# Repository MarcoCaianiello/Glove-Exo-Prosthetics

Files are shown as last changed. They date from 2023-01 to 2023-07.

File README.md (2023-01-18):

# Glove-Exo-Prosthetics
## Project Developed @[Icaros-Lab](https://www.icaros.unina.it/)

The aim of the project is to develop an Hand-Shape Exoskeleton to assist a thumb-missing patience with limited hand mobility. The Exoskeleton have to assist the user in the grasp motion. The patient is a 60+ y.o. male, thumb amputee with broken tendons on the remaining fingers. They can be barely moved without hurts the patience. He show problem also at his wrist, he has not a free wrist motion and he cannot put in that too much force.

The Exoskeleton is fully passive and body-powered. We have identified the flexion/extension of the elbow has movement to link with the hand closing/opening. The structure of the device will be compliace to increase the patience comfort while it is wearing. The motion is trasmitted by nylon wire that run through 3D printed tendon guide until the prosthetic thumb, the index and medium finger tip. The tendon guides has been designed to not affect the grasping even if they are placed in iternal part of the hand: palm, finger tips and phalanges. To convert the elbow extension to an hand grasp, we anchor a main tendon on the patience's bicep. A second anchor point, link to the finger tendons is placed on the forearm. In this way, the tendos are pulled when the elbow is extended.

To replace the absence of the thumb, two different designs are proposed. "Thumb whole with hinge" is a one-part thumb, printed using TPU that is using the inner elasticity of TPU to form its joints. "Thumb bottom part" & "thumb top part" are two parts, printed in resin, of a solid thumb and are connected using hinges printed in TPU as joints. Both designs are mounted on a 3d printed splint, that is supposed to hug the back of the hand and offer stability to the prosthetic thumb. The splint and the glove are sewn together. The splint design can be found as "Splint"

To keep the grasp, even when the patient's elbow is flexed, some latching mechanisms are proposed. "Linear latch" has the disadvantage that it needs to be more than double in length compared to the maximum travelling distance. "Rotating latch" needs calibration and scaling to match perfectly the travelling distance of the tendon. An exoskeleton developed by "openbionics" is using a latch mechanism that could be used and can be found [here](https://github.com/OpenBionics/Body-Powered-Exoskeleton-Glove).

### Notes
- The glove must be comfortable and garantee grip during grasping
- The glove can be coated by silicon to increase the grip
- In the grasping movement, the metacarpal flexion has to be included
- The Splint cannot be fully rigid, must introduce a compliance struture to increase the comfort and the fit
- To avoid the interaction of the tendons and the velcro strap used on the Splint, an upgrade could be to eliminate the velcro strap at all on the hand. In this case the thumb will be fixed on the glove.
- The use of a differential, pretension or elastic tendons must be explored to compensate the different finger lengths.

This project is based on this first [prototype](https://github.com/petrokal/ICAROS).

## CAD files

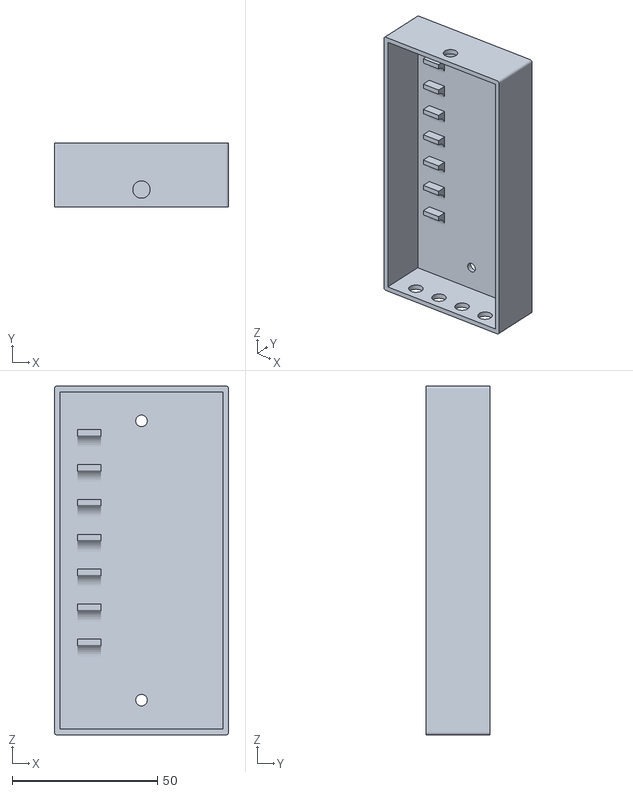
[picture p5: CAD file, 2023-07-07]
Latching_mechanism/Locker mechanism/Progetto locker con bottone/Scatola di fissaggio bottone v1.stl
60.0 x 22.0 x 120.0

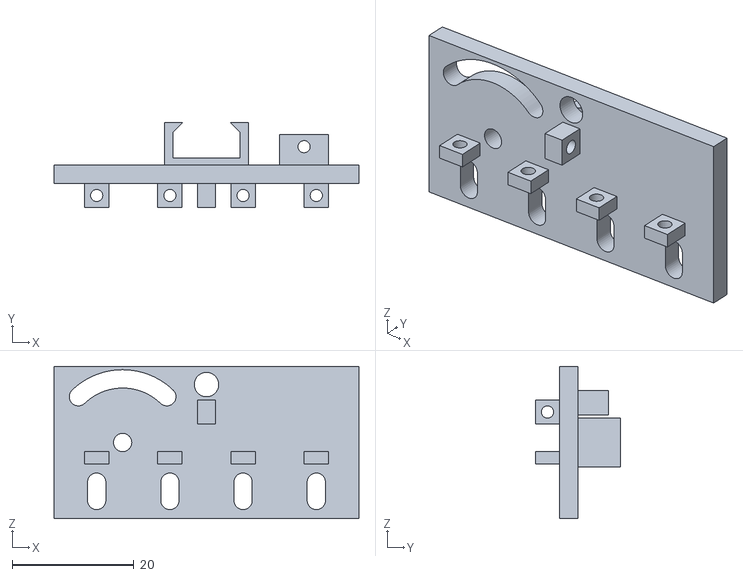
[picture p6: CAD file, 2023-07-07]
Latching_mechanism/Locker mechanism/Progetto locker-senza bottone/Base mobile v1.stl
50.0 x 14.0 x 25.0

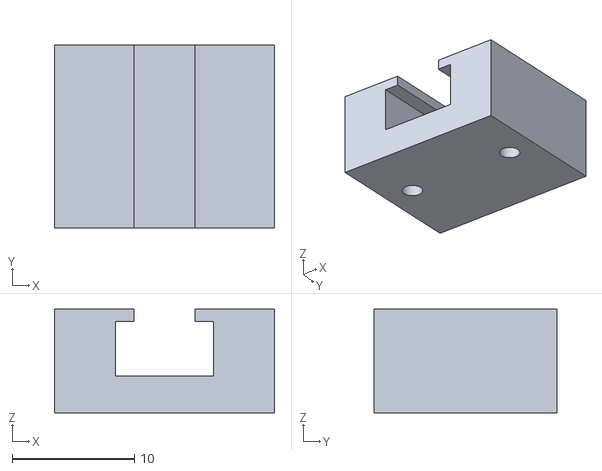
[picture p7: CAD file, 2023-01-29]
Latching_mechanism/openbionics/guide.stl
18.0 x 15.0 x 8.50

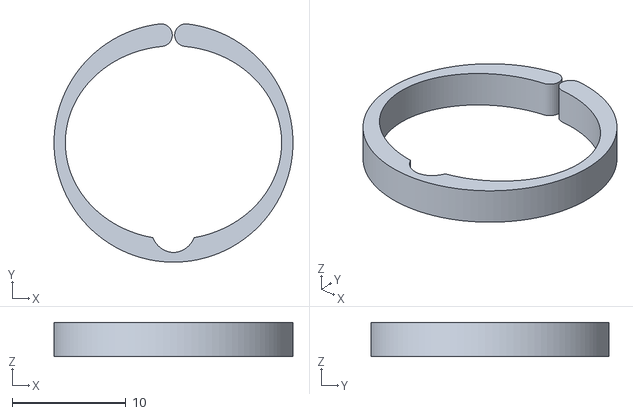
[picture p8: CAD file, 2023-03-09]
Tendon_guide/anchor_ring6.stl
21.0 x 20.9 x 3.00

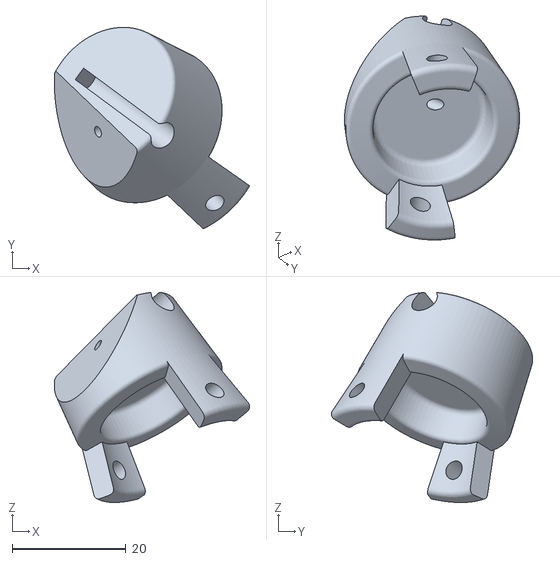
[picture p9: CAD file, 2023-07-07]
Thumb_Base_Wrist/Thumb_Base_mod.stl
34.4 x 35.4 x 37.0

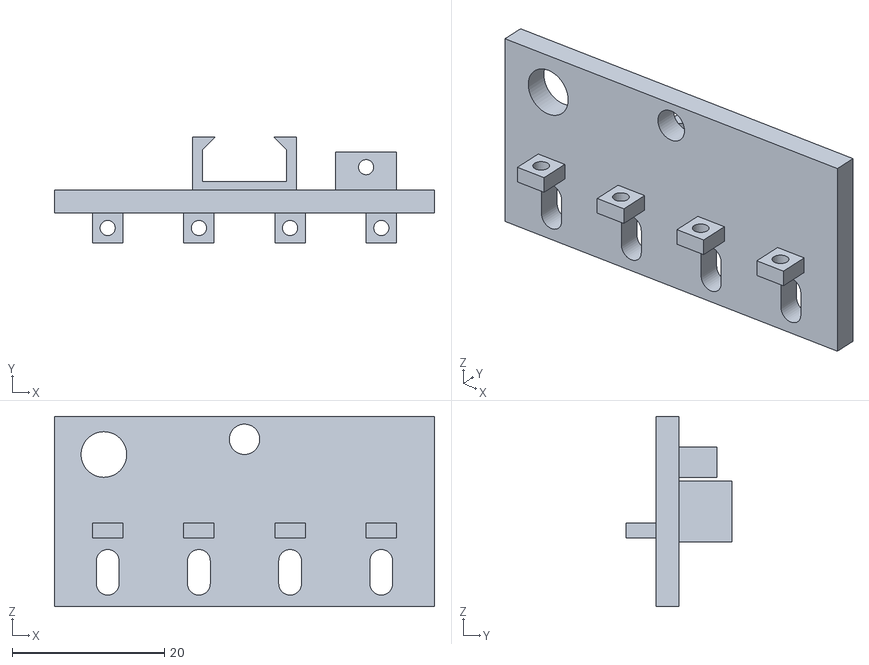
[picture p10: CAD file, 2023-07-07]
Latching_mechanism/Locker mechanism/Progetto locker con bottone/Base mobile bottone v1.stl
50.0 x 14.0 x 25.0

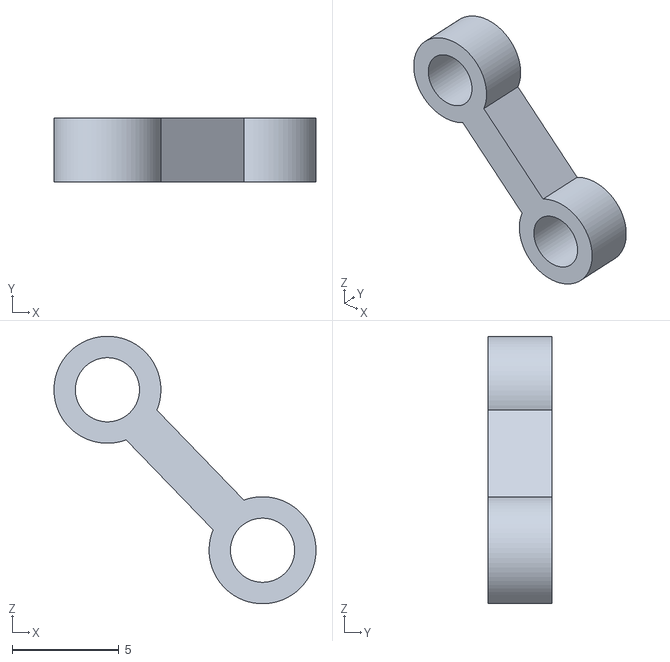
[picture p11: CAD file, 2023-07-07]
Latching_mechanism/Locker mechanism/Progetto locker-senza bottone/Perno rotante v1.stl
12.2 x 3.00 x 12.5

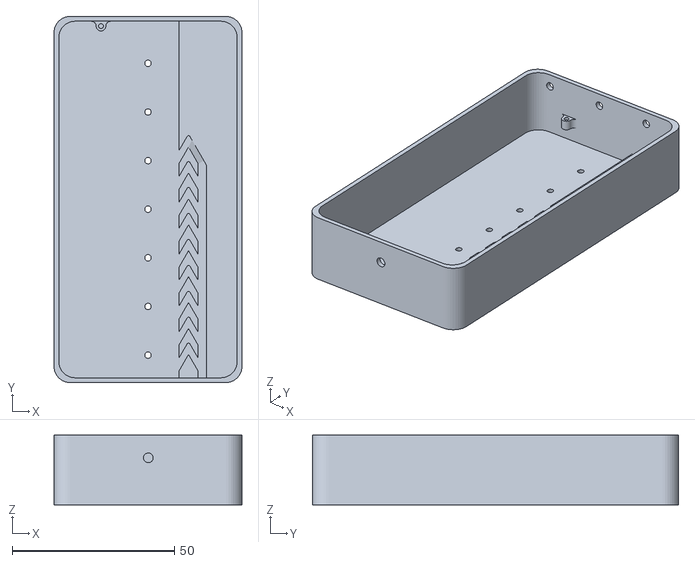
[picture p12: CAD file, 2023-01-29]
Latching_mechanism/openbionics/Box.STL
58.0 x 113.0 x 21.5

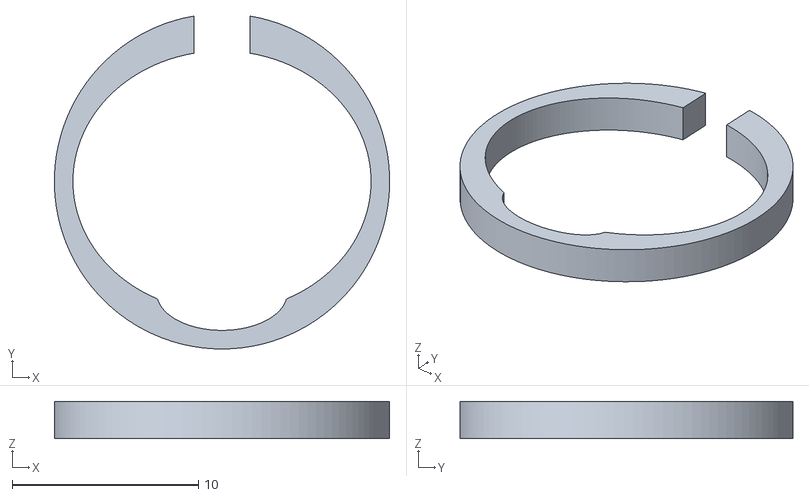
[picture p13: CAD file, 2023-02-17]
Tendon_guide/anchor_ring3.stl
18.0 x 17.9 x 2.00

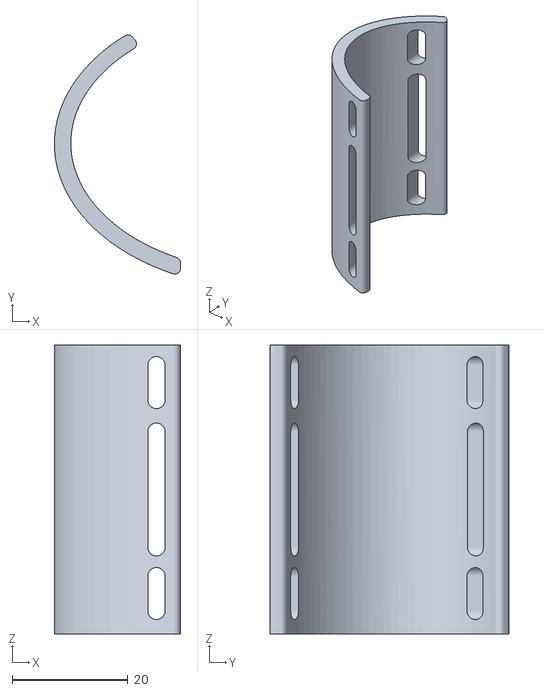
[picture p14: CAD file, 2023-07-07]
Thumb_Base_Wrist/Thumb_Wrist_Support_part2 v2.stl
21.8 x 41.4 x 50.0

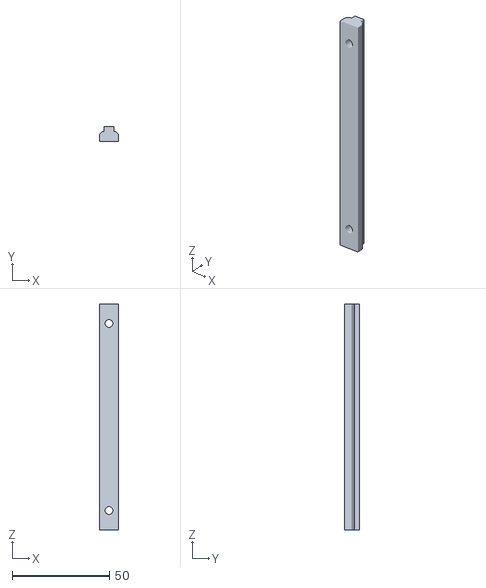
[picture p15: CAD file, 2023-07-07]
Latching_mechanism/Locker mechanism/Progetto locker-senza bottone/Guida lineare v1.stl
10.0 x 7.50 x 116.0

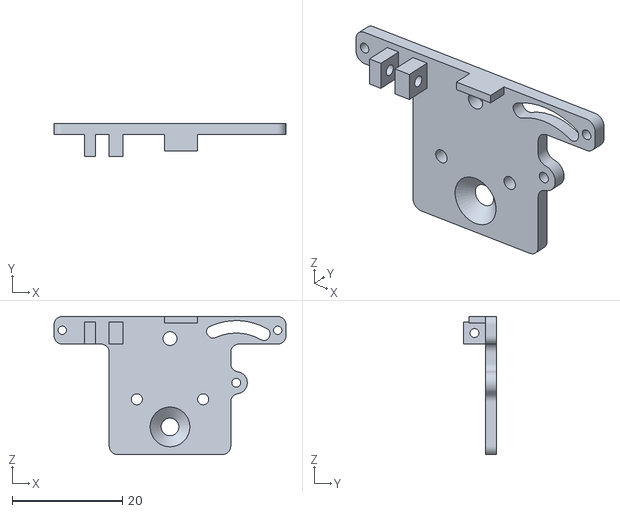
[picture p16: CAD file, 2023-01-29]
Latching_mechanism/openbionics/Rail attachment.STL
42.0 x 6.00 x 25.0

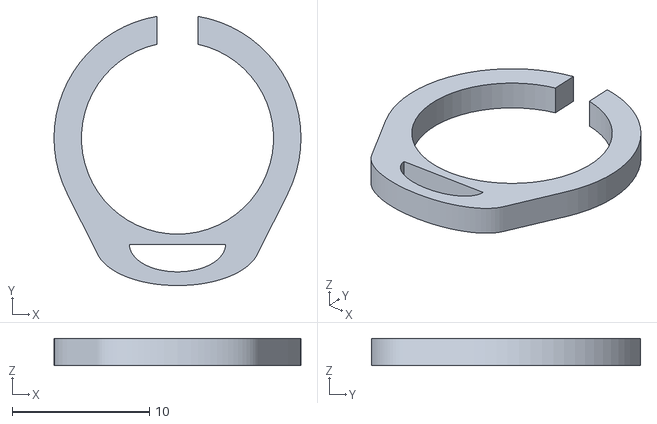
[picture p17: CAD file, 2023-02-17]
Tendon_guide/anchor_ring2.stl
18.0 x 19.6 x 2.00

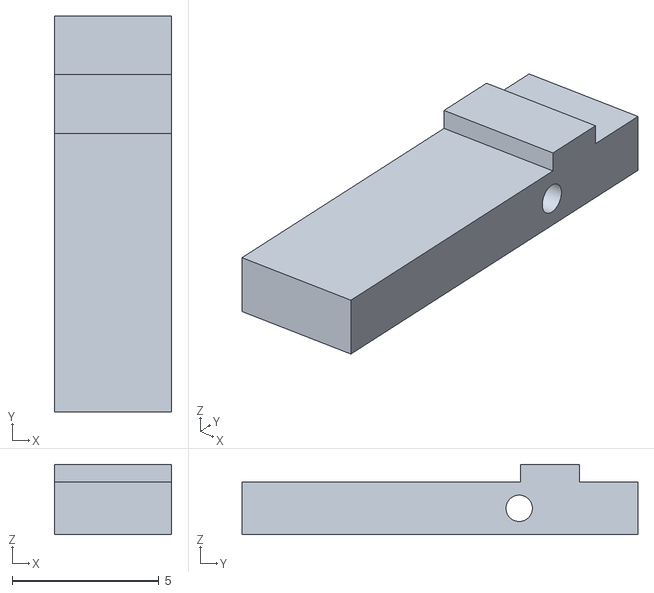
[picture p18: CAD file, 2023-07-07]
Thumb_Base_Wrist/Button v1.stl
4.00 x 13.5 x 2.40

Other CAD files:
Latching_mechanism/Locker mechanism/Progetto locker-senza bottone/Scatola di fissaggio v1.stl
Latching_mechanism/openbionics/Triangle.STL
Tendon_guide/anchor_ring.stl
Latching_mechanism/openbionics/Pulley 3.STL
Latching_mechanism/Locker - Button project.f3d
Latching_mechanism/Locker mechanism/Progetto locker con bottone/Progetto locker con bottone v3.f3d
Latching_mechanism/Locker mechanism/Progetto locker-senza bottone/Progetto locker senza bottone v9.f3d
Latching_mechanism/linear latch.f3d
Latching_mechanism/openbionics/Back attachment.STL
Latching_mechanism/openbionics/Lever.STL
Latching_mechanism/openbionics/RAIL .f3d
Latching_mechanism/openbionics/RAIL.stl
Latching_mechanism/openbionics/Ratchet 3.STL
Latching_mechanism/openbionics/guide.f3d
Latching_mechanism/rotating latch.f3d
Tendon_guide/anchor point finger.f3d
Tendon_guide/anchor_ring v2.f3d
Tendon_guide/anchor_ring v3.f3d
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

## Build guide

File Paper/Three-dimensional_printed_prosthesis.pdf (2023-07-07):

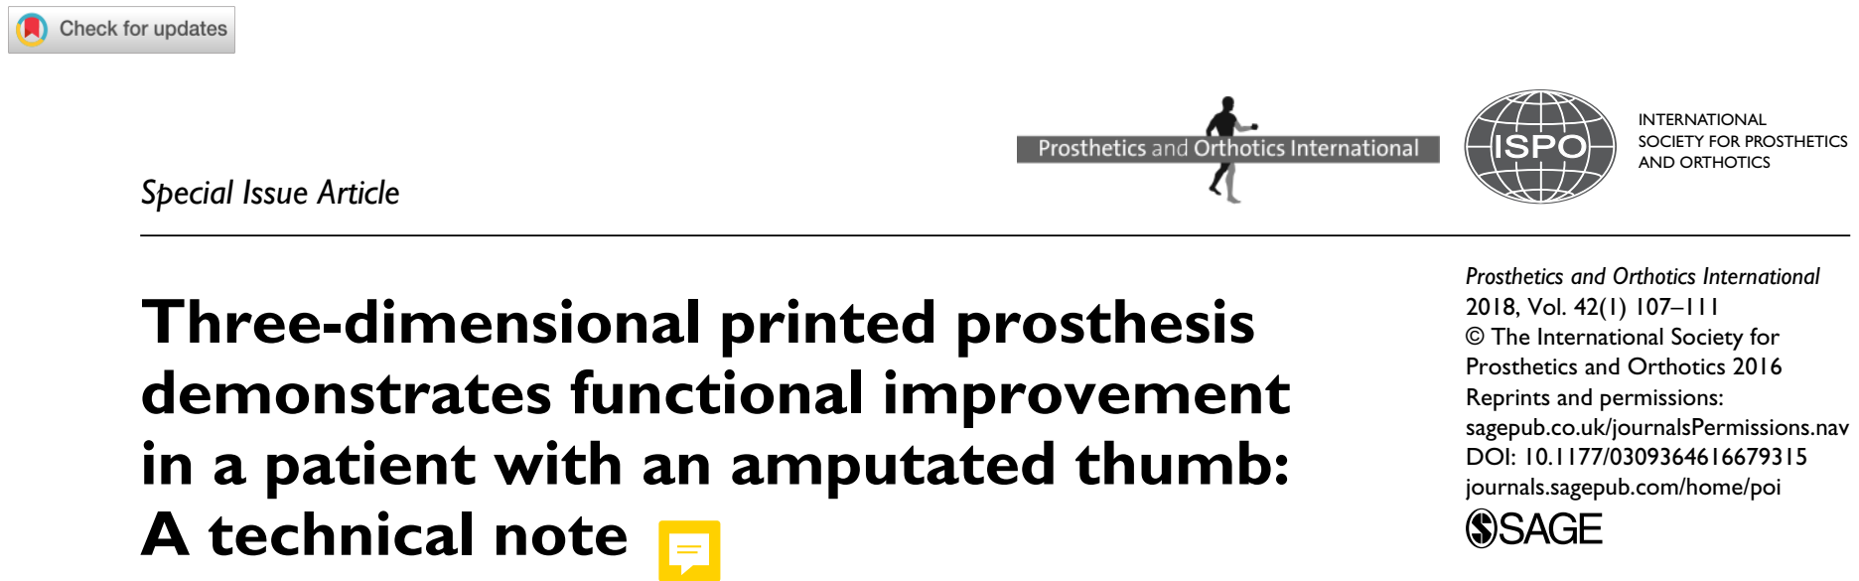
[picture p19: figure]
INTERNATIONAL SOCIETY FOR PROSTHETICS AND ORTHOTICS; https://doi.org/10.1177/0309364616679315; Prosthetics and Orthotics International 2018, Vol. 42(1) 107–111 © The International Society for Prosthetics and Orthotics 2016 Reprints and permissions: sagepub.co.uk/journalsPermissions.nav DOI: 10.1177/0309364616679315 journals.sagepub.com/home/poi; Three-dimensional printed prosthesis demonstrates functional improvement in a patient with an amputated thumb: A technical note; research-article2016; Special Issue Article

### Background and aim

Three-dimensional (3D) printers have been widely used in industry, biology, food, and medical fields and their use is growing explosively. 3D printers can produce easily modifiable objects without any fixed molding, which makes the objects unique.
3D printers have been used in the medical applications for the human body in the field of plastic surgery,¹ orthopedic implants,² dental devices,³ and orthoses and prostheses.⁴,5
Silicone finger prosthesis has been used for aesthetics,⁶ and acrylic finger prosthesis is used for hand function.⁷ Practically, finger prosthesis with a specific shape optimized to perform a specific movement is attractive to patients with finger amputation because it can be easily and inexpensively produced by 3D scanners and printers.

We report a case of a patient with an amputated thumb, who wore specifically shaped finger prostheses that were optimal to perform specific movements and were produced

Keun Ho Lee¹, Sung Jae Kim², Yong Ho Cha³, Jae Lim Kim⁴,

### Dong Kyu Kim⁴ and Sang Jun Kim⁴

Abstract
Background and Aim: Three-dimensional printer is widely used in industry, biology, and medical fields. We report a finger prosthesis produced by a three-dimensional scanner and printer for a 67-year-old man with a right thumb amputation above the metacarpophalangeal joint.
Technique: His right amputated and left intact hands were scanned with a three-dimensional scanner, and the left-hand image was rotated to the right side to design the right thumb prosthesis. The designed prosthesis was printed with a three-dimensional printer using the fused filament fabrication output system.
Discussion: The Jebsen–Taylor hand function test and Box and Block Test scores improved after application of the prosthesis. Most Quebec User Evaluation of Satisfaction with Assistive Technology results were “very satisfied,” and most Orthotics and Prosthetics Users’ Survey results were “very easy.” Preparing the prosthesis made by three-dimensional scanner and three-dimensional printer was faster and cheaper than preparing a conventional prosthesis.

Clinical relevance
Using three-dimensional scanning and printing technique, we can easily produce specifically shaped finger prostheses for specific movements in amputated patients with low cost.

Keywords
Prosthetic design, three-dimensional printing, medical application, finger prosthesis

Date received: 7 March 2016; accepted: 4 October 2016

1Department of Occupational Therapy, Samsung Medical Center, Seoul, Korea
2Department of Medical Device Management & Research, SAIHST, Sungkyunkwan University, Seoul, Korea
3Department of Physical Therapy, Samsung Medical Center, Seoul, Korea 4Department of Physical and Rehabilitation Medicine, Samsung Medical Center, Sungkyunkwan University School of Medicine, Seoul, Korea Corresponding author:
Sang Jun Kim, Department of Occupational Therapy, Samsung Medical Center, Irwonro, Gangnamgu, Seoul 135-710, Korea.
Email: catedral.sjk@gmail.com

679315 POI0010.1177/0309364616679315Prosthetics and Orthotics InternationalLee et al. (http://crossmark.crossref.org/dialog/?doi=10.1177%2F0309364616679315&domain=pdf&date_stamp=2016-12-20)

108 | Prosthetics and Orthotics International 42(1)

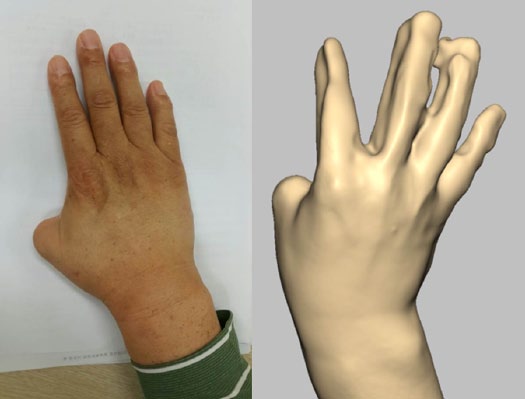
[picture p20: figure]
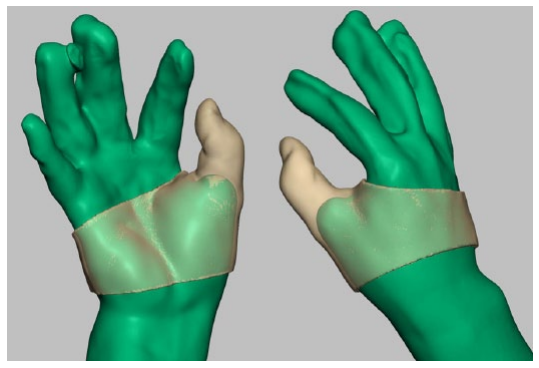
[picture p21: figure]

by a 3D scanner and printer and allowed improved functioning.

### Technique

A 67-year-old man visited our outpatient department due to a right thumb amputation above the metacarpophalangeal joint in August 2015 (Figure 1). The amputation had happened during work in 1970. He also had gait difficulties with ataxia and mild right-hand weakness due to a left anterior inferior cerebral infarction in 1999. Motor grade of the right upper hand by manual muscle test was good, and a sensory test was normal. He performed most gross motor activities using his right hand because he was righthanded, but he had a difficulty with fine motor activities using his right hand because of the right thumb amputation and mild weakness. He had lived without a prosthesis since the right thumb amputation 45 years ago because no ready-made prostheses met his needs in terms of function and cost. He had to grasp small objects with his left hand or with assistance from others.

### Designing and printing the prosthesis

The patient stated that the most uncomfortable daily activities were writing a letter and picking up a small object. Based on these responses, individualized prostheses were designed to ease the tripod grasp for writing and grasping a small object. His right hand was scanned with a 3D scanner (Artec™ Eva, Artec Group, Luxembourg) at 16frames/s (Figure 1). The left hand was also scanned in the tripod grasp postures using the same scanner. These scanned data of the left hand were rotated from the left to right side to design the right thumb prosthesis. The right finger

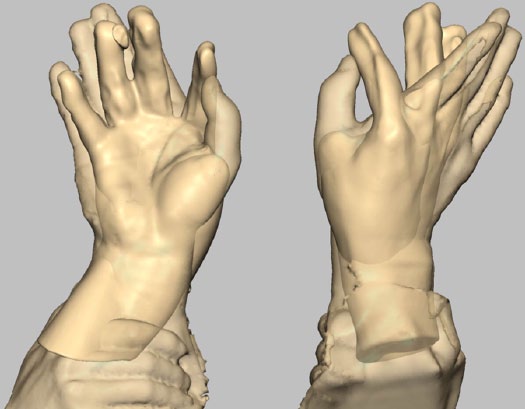
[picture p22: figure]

prosthesis was designed by overlapping the right amputated hand with the flipped left intact hand (Figure 2), subtracting the overlapped part, and adding the contacted part (Figure 3). All design procedures were performed using the Touch Haptic Stylus (3D Systems Corp., Rock Hill, SC, USA) and Geomagic Freeform (3D Systems Corp.) software.
The designed prosthesis was printed with FB9600 (TPC Mechatronics Inc., Incheon, Korea) using the fused filament fabrication output system, which involved stacking up melted flexible thermoplastic elastomer filaments (Shenzhen Esun Industrial Co., Ltd, Shenzhen, China) layer by layer. These filaments were non-toxic and highly flexible (flexural modulus of 8.1MPa). After printing out, the finger prosthesis for tripod grasp was given to the patient. To prevent slippage and increase the grip force, the surface of the thumb prosthesis was designed to have a non-slip pattern (Figure 4). The suspension was designed as a band for close attachment to the hand. The patient did not receive occupational therapy to train writing because he adapted easily to using the finger prosthesis.

Figure 1. A right thumb was amputated above the metacarpophalangeal joint and this was scanned with a 3D scanner (Artec™ Eva, Artec Group, Luxembourg) at 16 frames/s.

Figure 2. The scanned data of the left intact hand were rotated from the left to right side and overlapped with the right amputated hand to design the prosthesis.

Figure 3. A right-hand prosthesis was designed by subtracting the overlapped part and adding the contacted part.

Lee et al. | 109

### Evaluation of prosthesis

The Jebsen–Taylor hand function test (JTT) and the Box
and Block Test (BBT) were performed to evaluate right-hand function in the occupational therapy department. The JTT consists of seven items to evaluate the gross and fine hand motor functions and measures the elapsed time for specific tasks.⁸ The BBT is used to measure agility of the upper extremities and to evaluate a worker’s occupational capacity by measuring how many blocks can be moved in 1min.⁹ The patient performed daily activities using the prosthesis for 1month and revisited our outpatient clinic on 5 October. He underwent JTT and BBT and was tested using the Quebec User Evaluation of Satisfaction with Assistive Technology (QUEST) to determine satisfaction with the prosthesis. The QUEST consists of six items in the area of assistive devices and four items in the area of service parts and scores range from 12 to 60.¹⁰ The service part was omitted because it was not appropriate for the purpose of this study.
The Orthotics and Prosthetics Users’ Survey (OPUS) was used to evaluate performance of daily activities and satisfaction with the tripod-type prosthesis. Upper extremity functional status is evaluated using 19 items on the OPUS (0–57 points), and a score of 27 points represents a moderate level of upper extremity function.¹¹
Written informed consent was obtained from the patient, and this research was approved by the Institutional Review Board of our hospital (IRB No. 2014-12-013). The elapsed time and cost for designing and making the prosthesis were about 48h and US$50.
The BBT score of the patient was 17 before using the prosthesis and 21 after application of the prosthesis. The prosthesis allowed easier grasping of the box and a faster tip pinch (Figure 5).
The JTT results showed that elapsed time decreased for all the items except stacking checkers (Table 1). Elapsed time and accuracy of writing improved because the tripod grasp with the finger prosthesis made holding a pencil easier and more delicate writing was possible. Times for card turning and picking up small objects shortened due to opposition and pinching movements of the thumb with the finger prosthesis. Simulated feeding improved because the prosthesis fixed a spoon between the thumb and the second finger. The QUEST satisfaction result was 36 of a total 40 points and most items on the QUEST were “very satisfied” or “quite satisfied.”
Most items except washing the face and tying a shoe on the OPUS test were marked “easy” or “very easy.” The OPUS results revealed “not available (NA)” for washing the face and “difficult” for tying a shoe and using scissors. The patient wore this finger prosthesis all the time with no complications because he felt the prosthesis was light, close-fitting, easy to don and remove, and gave him no skin troubles.

### Discussion

From this study, we applied specifically shaped finger prosthesis made with a 3D scanner and printer designed to perform specific movements for a patient who had his

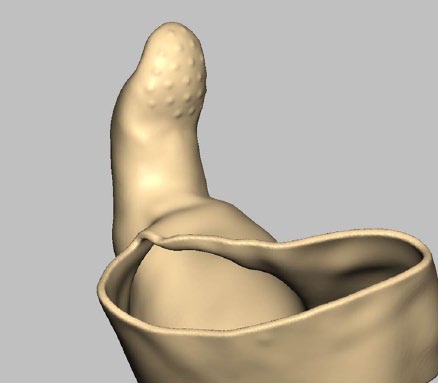
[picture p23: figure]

Figure 4. The surface of the thumb prosthesis was designed to have a non-slip pattern to prevent slippage and increase the grip force.

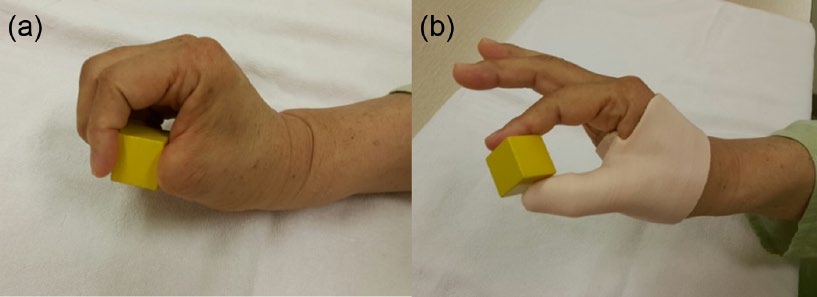
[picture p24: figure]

Figure 5. A patient grasps a small box (a) without a prosthesis and (b) with a prosthesis. The prosthesis allowed easier grasping of the box and a faster tip pinch, which increased the BBT score.

110 | Prosthetics and Orthotics International 42(1)

thumb amputated and achieved better functional improvement and satisfaction from the patient.
We easily made the finger prosthesis with the same position taken during a specific action by mirroring the position of the contralateral hand while simulating the action. This simple technique can make the patients produce their prosthesis easily by themselves at any time through a stored design file. In addition, the 3D design process can easily alter diverse changes in finger positions and make a variety of prosthetic hand shapes. This lowers the price and enables patients to make their own prosthesis with diverse finger positions regardless of skill.
In the OPUS test, 16 of 19 items were “easy” or “very easy.” Brush/comb hair, open door with knob, carry laundry basket, and put on and take off prosthesis were “very easy” and put on socks and fold bath towel were “easy.” This means that the tripod-type prosthesis made grasping easier. All the items on the JTT, except stacking checkers, improved after applying the prosthesis. The patient used his second and third fingers in a lateral pinching motion to stack checkers without the prosthesis. However, he pinched the tips of the prosthetic thumb and second finger to stack checkers. He could not extend his prosthetic thumb voluntarily, so he had difficulty stacking the checkers. Thus, the angle of the prosthetic thumb must be adjusted to ease stacking the checkers.
Considering that this technique has the advantage of adjusting the optimal position of finger joints for specific tasks, it will be useful in cases of amputation above the proximal interphalangeal joint.
It took about 48 h to scan the hand and design and print the prosthesis at a cost of about US$50. This was faster and cheaper than preparing a conventional prosthesis. Acrylic prosthesis by the thermoplastic technique can be made quickly but does not provide optimal angles for specific functions, such as writing or grasping. To produce acrylic prosthesis with optimal angles, specific molds and casts must be made, which require more time and expense. Another advantage of using the 3D printer is that the stored 3D image files can be easily modified, which cannot be achieved with the thermoplastic technique.
In conclusion, we produced specifically shaped finger prostheses for specific movements using a 3D scanner and printer for a patient with an amputated thumb who achieved better function and satisfaction. We hope that 3D scanners and printers will be widely used to prepare finger prostheses with little time and very low cost.

### Key points

- We easily made the finger prosthesis with the same position taken during a specific action by mirroring the position of the contralateral hand while simulating the action.
- This simple technique can make the patients produce their prosthesis easily by themselves at any time through a stored design file and easily alter diverse changes in finger positions.
- This technique lowers the price of prosthesis and enables patients to make their own prosthesis with diverse finger positions regardless of skill.

Author contribution
All authors contributed equally in the preparation of this manuscript.

Declaration of conflicting interests
The author(s) declared no potential conflicts of interest with respect to the research, authorship, and/or publication of this article.

Funding
The author(s) disclosed receipt of the following financial support for the research, authorship, and/or publication of this article: This work was supported by the grant of the Korea Health Technology R&D Project through the Korea Health Industry Development Institute (KHIDI), funded by the Ministry of Health & Welfare, Republic of Korea (grant number: HI14C3229) and ICT R&D program of MSIP/IIPT (Grant No. B0101-16-1081).

References
1. Kamali P, Dean D, Skoracki R, et al. The current role of three-dimensional printing in plastic surgery. Plast Reconstr Surg 2016; 137(3): 1045–1055.
2. Malik HH, Darwood AR, Shaunak S, et al. Three-dimensional printing in surgery: a review of current surgical applications. J Surg Res 2015; 199(2): 512–522.

Table 1. Jebsen–Taylor hand function test before and after the application of the hand prosthesis.

| Before the application (s) | After the application (s)
Writing | 39.52 | 34.48
Card turning | 14.18 | 11.73
Picking up small object | 61.30 | 57.45
Simulating feeding | 20.81 | 18.15
Stacking checkers | 24.56 | 38.80
Lifting large lightweight objects | 8.95 | 8.10
Lifting large heavy objects | 10.56 | 10.26

Lee et al. | 111
3. Alharbi N, Osman R and Wismeijer D. Effects of build
direction on the mechanical properties of 3D-printed complete coverage interim dental restorations. J Prosthet Dent 2016; 115: 760–767.
4. Dombroski CE, Balsdon ME and Froats A. The use of a low cost 3D scanning and printing tool in the manufacture of custom-made foot orthoses: a preliminary study. BMC Res Notes 2014; 7: 443.
5. Gretsch KF, Lather HD, Peddada KV, et al. Development of novel 3D-printed robotic prosthetic for transradial amputees. Prosthet Orthot Int 2015; 40: 400–403.
6. Raghu KM, Gururaju CR, Sundaresh KJ, et al. Aesthetic finger prosthesis with silicone biomaterial. BMJ Case Rep. Epub ahead of print 3 December 2013. DOI: 10.1136/bcr-2013-010385.
7. Reddy KRK, Bandela V, Bharathi M, et al. Acrylic finger prosthesis: a case report. J Clin Diagn Res 2014; 8(8): ZD07–ZD08.
8. Sears ED and Chung KC. Validity and responsiveness of the Jebsen-Taylor hand function test. J Hand Surg Am 2010; 35(1): 30–37.
9. Desrosiers J, Bravo G, Hebert R, et al. Validation of the Box and Block Test as a measure of dexterity of elderly people: reliability, validity, and norms studies. Arch Phys Med Rehabil 1994; 75(7): 751–755.
10. Demers L, Monette M, Lapierre Y, et al. Reliability, validity, and applicability of the Quebec User Evaluation of Satisfaction with assistive Technology (QUEST 2.0) for adults with multiple sclerosis. Disabil Rehabil 2002; 24(1– 3): 21–30.
11. Heinemann AW, Bode RK and O’Reilly C. Development and measurement properties of the Orthotics and Prosthetics Users’ Survey (OPUS): a comprehensive set of clinical outcome instruments. Prosthet Orthot Int 2003; 27(3): 191–206.

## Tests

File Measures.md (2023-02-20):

# Patience Measure
## Distance
- |Thumb - Wrist| = 4 cm
- |Index - Wrist| = 13 cm
- |Middle - Wrist| = 13.5 cm
- |Anular - Wrist| = 12 cm
- |Little - Wrist| = 10 cm
- |Wrist - Elbow| = 20 cm
- |Elbow - Shoulder| = 20 cm
- |Palm Width| = 8.5 cm
## Circonference
- (Hand Palm) = 20/21 cm
- (Wrist) = 18 cm
- (Forarm) = 23 cm
- (Bicep) = 26 cm

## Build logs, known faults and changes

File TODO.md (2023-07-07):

# Glove Exo-Prosthetics
## TODO List
- [ ] Anchor Point
    - ~Anchor Point ad Anello intorno al dito per migliorare la stabilità ed evitare di stressare il tessuto del guanto~
    - Uso di un nastro di velcro per permettere una maggiore adattabilità della soluzione.
    - Le precedenti TendonGuide verranno riutilizzate e fissate sul velcro.
    - [Velcro Acquistato](https://amzn.eu/d/cbKXSQC)
    - Spostare quelli sul palmo più vicini al polso
    - Evitare interazioni con il Splint e il suo fissaggio
- [ ] Sostituire i tendini di Nylon Trasperente con quelli Neri
- [ ] Splint/Supporto Giallo
    - Creare un supporto con un elemento elastico sul dorso e rigido ai lati per una migliore vestibilità
    - Cercare di evitare velcro sul palmo
- [ ] Guanto e Sostegno al polso
    - [Nuovo Guanto Acquistato](https://www.amazon.it/gp/product/B098JTQS9J/ref=ppx_yo_dt_b_asin_title_o00_s00?ie=UTF8&psc=1)
    - Nuovo supporto Polso presente nel lab tra le cose del progetto
- [ ] Rivestimento in silicone
    - [Rivestimento Acquistato](https://www.amazon.it/dp/B09QMDMCKF?psc=1&smid=A3IFH27SO9AZ3W&ref_=chk_typ_imgToDp)
    - Ricercare un modo per rivestire il palmo e le dita con un elemento in silicone per aumentare il grip della presa
- [ ] Deadzone
    - Dimensionare il meccanism di chiusura del palmo in modo da avere una presa salda anche se il braccio non è completamente disteso. (Completa chiusura != Completa distensione braccio)
- [ ] Locker
    - Simile a quello della [Open Bionic](https://www.youtube.com/watch?v=sHJ_ZJMQ4vw)
    - Punti Fondamentali: Discreto, Vari livelli di chiusura, Minor manutenzione possibile
- [ ] Metacarpo
    - Implementare la flessione del metacarpo nell'esoscheletro
    - Mantenere come forza antagonista, l'elasticità del materiale (TPU)

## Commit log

2023-01-29 Update Finger Anchor Design
    [anchor_ring v2.f3d]
2023-02-17 upload new anchor ring versions
    [anchor_ring v3.f3d, anchor_ring.stl, anchor_ring2.stl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]
2023-03-09 New anchor_ring_v6
    [anchor_ring v6.f3d, anchor_ring6.stl]
2023-04-05 Introducing Velcro Strap
2023-07-07 Update Repo
    [Button v1.stl, Tendon_Lock_Base v1.stl, Tendon_Lock_Base_Button v1.stl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]
